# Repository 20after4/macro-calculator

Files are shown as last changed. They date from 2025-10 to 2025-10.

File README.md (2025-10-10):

# MacroCalculator

Custom Mechanical USB Keypad + Standalone Calculator written in MicroPython

## Hardware:

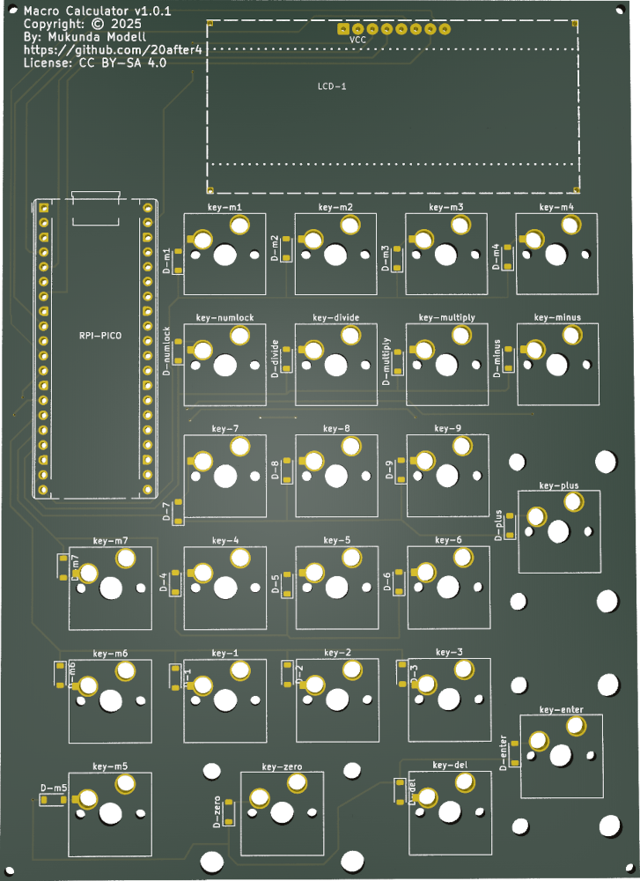
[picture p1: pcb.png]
Illustration of the circuit board PCB
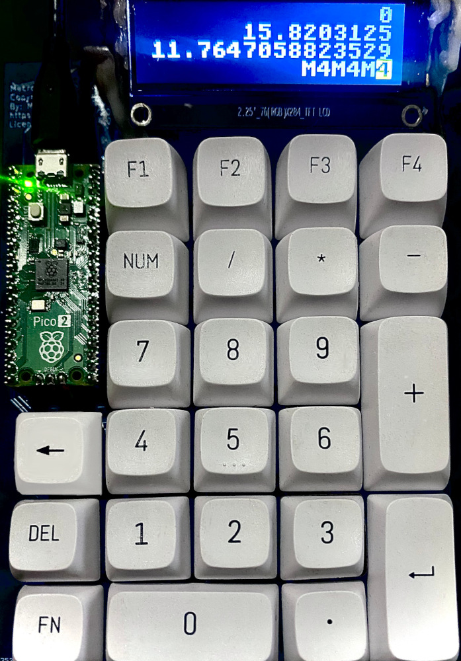
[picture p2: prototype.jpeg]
Photo of the prototype Prototype
 

* Custom 24 Key Matrix PCB
    * Supports hot-swapable MX-style key switches
    * Hand solderable (Difficulty: medium-high due to small surface mount diodes)
    * Standard PC Numpad Keys
    * 7 extra macro keys
    * Sockets for MCU and LCD via pin headers.
* RPi Pico 2 (RP2350 MCU)
* 72x284 resolution ST7789 LCD Screen: 16px font = 4 lines x 17 characters

## Software / Firmware

Custom Python App running on [lvgl/lv_micropython](https://github.com/lvgl/lv_micropython) firmware.

The NumLock key toggles between two modes:

* Calc mode:
  * Basic calculator functionality
  * 17 digits of decimal precision
  * Basic expression evaluation
  * Named variables assignable to the macro keys
  * Scrollable history buffer
* Keypad mode:
  * Basic USB HID Numpad
  * Macro keys programmable with MicroPython for nearly unlimited flexibility.

### Acknoledgements

Here I credit the projects that made this one possible. This project draws on these other open source projects for inspiration and some of the components used in developing macro-calc:

* Raspberry Pi Pico - The RP2040 and successors have proven to be a very affordable and accessible microcontroller development platform which has significantly lowered the barrier to entry for embedded development.
* [MicroPython](https://www.micropython.org/): The programming language runtime and embedded firmware infrastructure.
* [LVGL](https://lvgl.io/) - Graphics API for embedded devices which I've utilized in order to support the LCD display in this project.
* [lvgl/lv_micropython](https://github.com/lvgl/lv_micropython) is a fork of micropython designed for building microcontroller Firmware with integrated LVGL graphics capabilities compiled into the micropython runtime. This is the foundation I've used to build the firmware for this project.
* [lvgl_micropython](https://github.com/lvgl-micropython/lvgl_micropython) deserves an honorable mention. This is an alternative fork, based on the previously mentioned project.  Although I don't currently use this fork to build my firmware, I have learned quite a lot about TFT Display chips from studying their source code, issues and discussions on github and on the lvgl forums.
* [mpy-dev/micropython-decimal-number](https://github.com/mpy-dev/micropython-decimal-number) provides
  a basis for sane decimal arithmatic. This has proven very helpful for the calculator portion of this project. Floating point math isn't a good fit for a general purpose calculator.

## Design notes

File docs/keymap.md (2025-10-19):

keymap.py contains a list with all of the key metadata.

The layout of the keys list is arranged according to the physical key matrix
starting at the bottom row with F17 through ENTER.   Positions that are not
connected to a key switch are filled with the value None so that the matrix
remains rectangular.   There are 6 rows with 5 columns.  There are however,
only 4 keys in each matrix column. Coercing the data structure to match the
physical wiring of the key matrix allows for more efficient key scanning.
Specifically, it allows us to deduce the keycode from simply multipling
row * column  to get the index into the keys list so that key metadata can
be accessed with a quick lookup, without scanning the array and without the
memory overhead of using a hash table.

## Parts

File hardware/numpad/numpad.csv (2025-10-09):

Id | Designator | Footprint | Quantity | Designation | Supplier and ref
1 | LCD-1 | 2.25in LCD DISPLAY 284x76 | 1 | 2.25in LCD
2 | key-m6,key-m5,key-2,key-del,key-divide,key-m3,key-m1,key-9,key-4,key-multiply,key-6,key-m4,key-m2,key-minus,key-8,key-5,key-m7,key-3,key-1,key-numlock,key-7 | SW_Cherry_MX_1.00u_PCB_HOTSWAP | 21 | SW_Cherry_MX_1.00u_PCB_HOTSWAP
3 | D-m1,D-m2,D-m7,D-enter,D-m6,D-divide,D-m5,D-m4,D-7,D-m3,D-multiply,D-3,D-6,D-plus,D-8,D-1,D-9,D-del,D-numlock,D-2,D-4,D-5,D-minus,D-zero | D_SOD-123 | 24 | D_SOD-123
4 | key-enter,key-plus | SW_Cherry_MX_2.00u_Vertical_PCB | 2 | SW_Cherry_MX_2.00u_Vertical_PCB
5 | RPI-PICO | RaspberryPi_Pico_Common_THT | 1 | RaspberryPi_Pico_Common_THT
6 | key-zero | SW_Cherry_MX_2.00u_PCB | 1 | SW_Cherry_MX_2.00u_PCB

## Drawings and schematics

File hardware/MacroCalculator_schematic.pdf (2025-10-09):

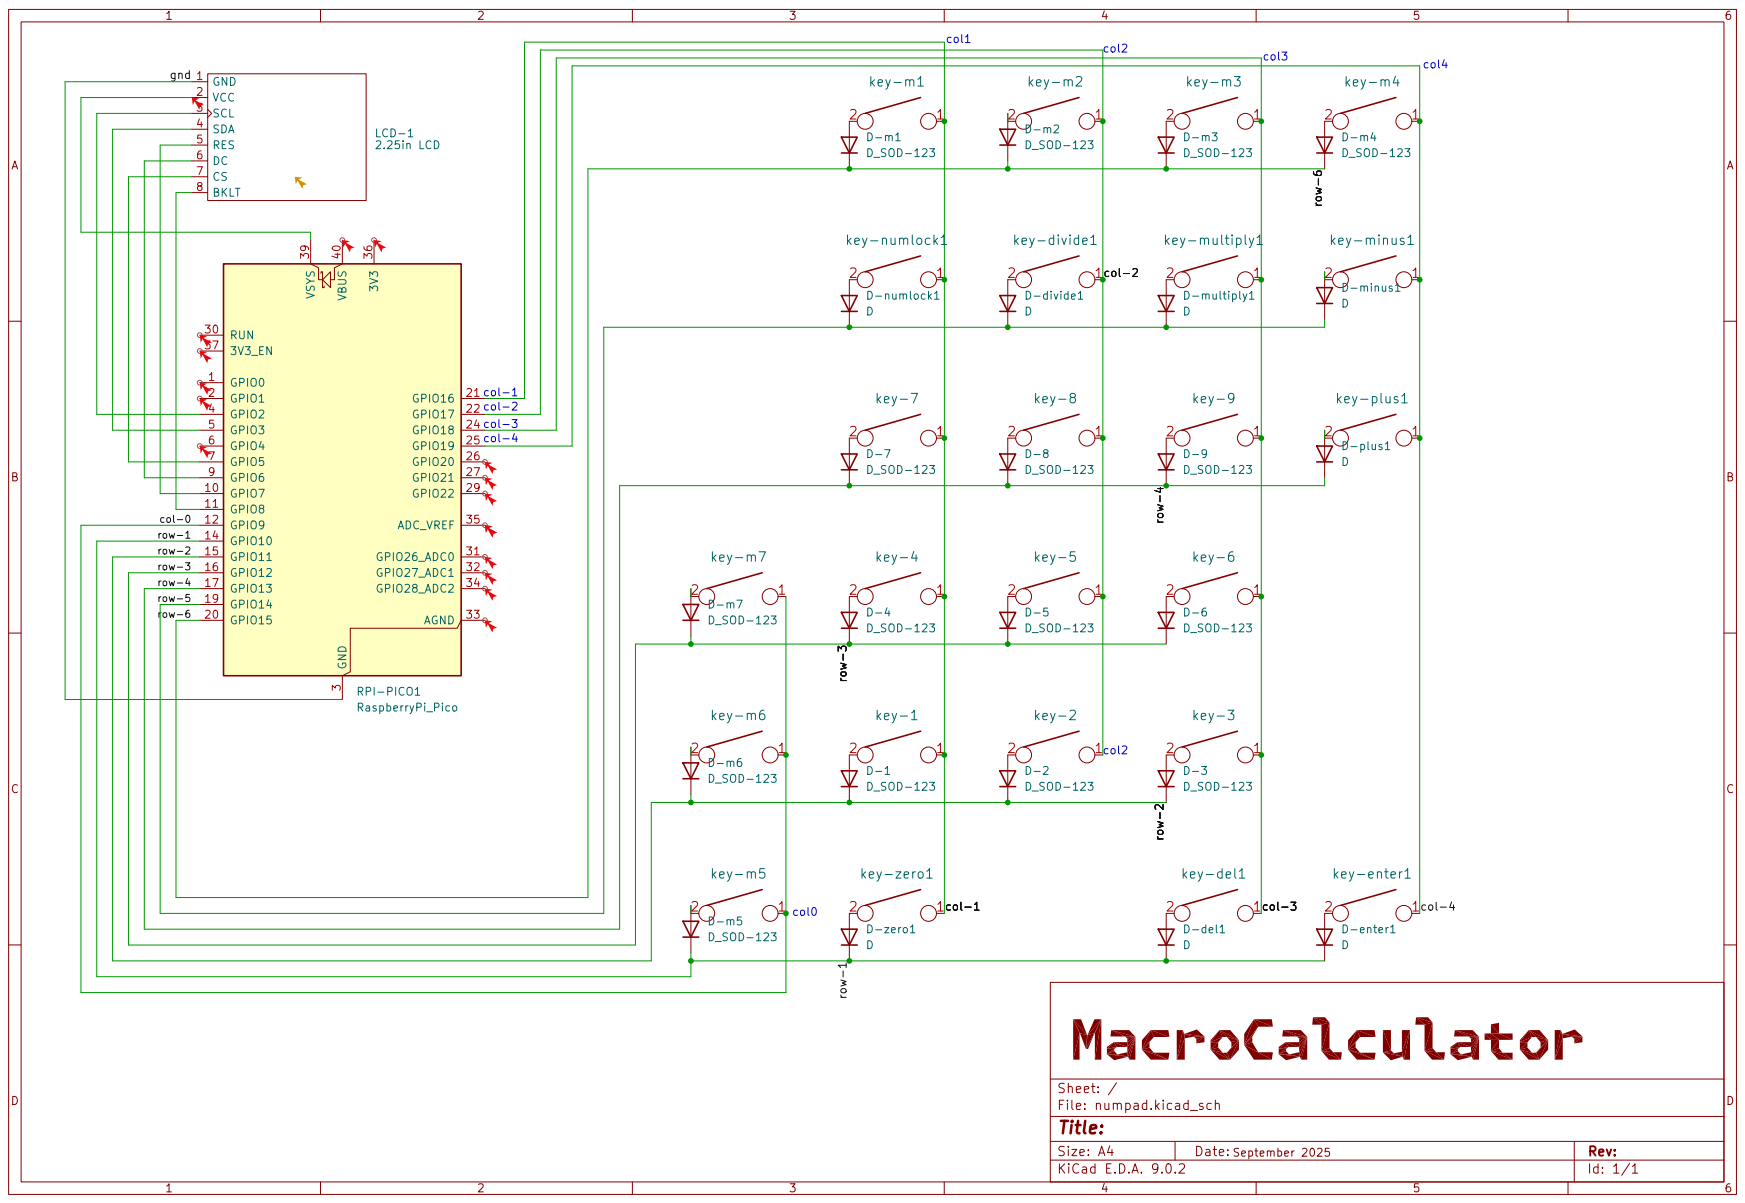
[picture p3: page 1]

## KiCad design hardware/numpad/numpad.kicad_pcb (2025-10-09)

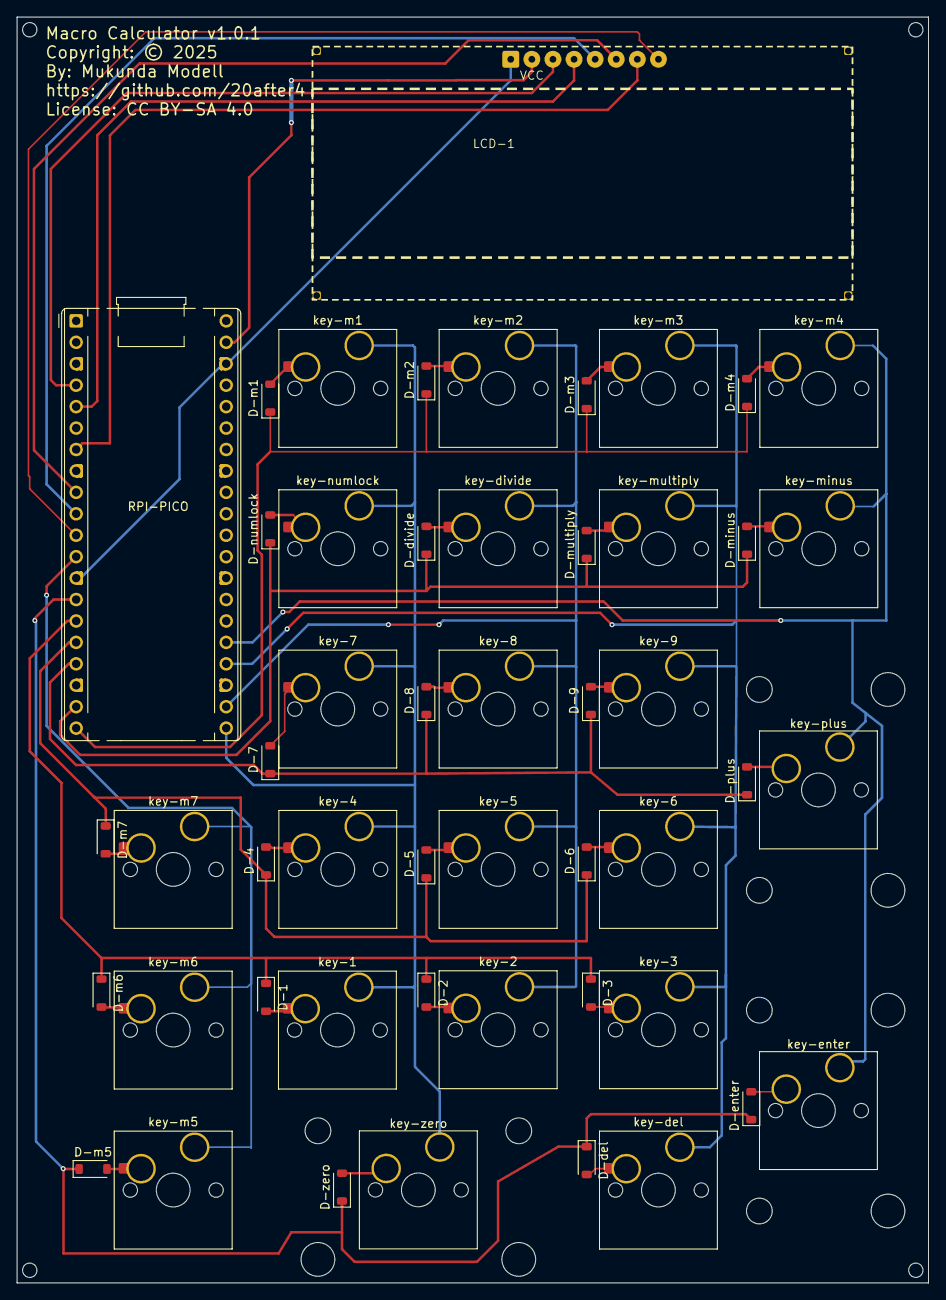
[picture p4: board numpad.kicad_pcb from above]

Board: 2 copper layers, 108.0 x 150.0 mm, 50 parts (0 on the bottom side), 43 nets.

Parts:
D-1, D-2, D-3, D-4, D-5, D-6, D-7, D-8, D-9: D_SOD-123
D-del: D_SOD-123
D-divide: D_SOD-123
D-enter: D_SOD-123
D-m1, D-m2, D-m3, D-m4, D-m5, D-m6, D-m7: D_SOD-123
D-minus: D_SOD-123
D-multiply: D_SOD-123
D-numlock: D_SOD-123
D-plus: D_SOD-123
D-zero: D_SOD-123
LCD-1: 2.25in LCD; 2.25in LCD DISPLAY 284x76
RPI-PICO: RaspberryPi_Pico_Common_THT
key-1, key-2, key-3, key-4, key-5, key-6, key-7, key-8, key-9: SW_Cherry_MX_1.00u_PCB_HOTSWAP
key-del: SW_Cherry_MX_1.00u_PCB_HOTSWAP
key-divide: SW_Cherry_MX_1.00u_PCB_HOTSWAP
key-enter: SW_Cherry_MX_2.00u_Vertical_PCB
key-m1, key-m2, key-m3, key-m4, key-m5, key-m6, key-m7: SW_Cherry_MX_1.00u_PCB_HOTSWAP
key-minus: SW_Cherry_MX_1.00u_PCB_HOTSWAP
key-multiply: SW_Cherry_MX_1.00u_PCB_HOTSWAP
key-numlock: SW_Cherry_MX_1.00u_PCB_HOTSWAP
key-plus: SW_Cherry_MX_2.00u_Vertical_PCB
key-zero: SW_Cherry_MX_2.00u_PCB

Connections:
LCD-BACKLIGHT: LCD-1.8, RPI-PICO.11
LCD-CS: LCD-1.7 (BKLT), RPI-PICO.7
LCD-DC: LCD-1.6 (CS), RPI-PICO.9
LCD-RESET: LCD-1.5 (RES), RPI-PICO.10
unnamed: D-1.2 (A), key-1.2
unnamed: D-2.2 (A), key-2.2
unnamed: D-3.2 (A), key-3.2
unnamed: D-4.2 (A), key-4.2
unnamed: D-5.2 (A), key-5.2
unnamed: D-6.2 (A), key-6.2
unnamed: D-7.2 (A), key-7.2
unnamed: D-8.2 (A), key-8.2
unnamed: D-9.2 (A), key-9.2
unnamed: D-m1.2 (A), key-m1.2
unnamed: D-m2.2 (A), key-m2.2
unnamed: D-m3.2 (A), key-m3.2
unnamed: D-m4.2 (A), key-m4.2
unnamed: D-m5.2 (A), key-m5.2
unnamed: D-m6.2 (A), key-m6.2
unnamed: D-m7.2 (A), key-m7.2
SPI-CLK: LCD-1.3 (SCL), RPI-PICO.4
SPI-DATA: LCD-1.4 (SDA), RPI-PICO.5
col-0: RPI-PICO.12, key-m5.1, key-m6.1, key-m7.1
col-1: RPI-PICO.21, key-1.1, key-4.1, key-7.1, key-m1.1, key-numlock.1, key-zero.1
col-2: RPI-PICO.22, key-2.1, key-5.1, key-8.1, key-divide.1, key-m2.1
col-3: RPI-PICO.24, key-3.1, key-6.1, key-9.1, key-del.1, key-m3.1, key-multiply.1
col-4: RPI-PICO.25, key-enter.1, key-m4.1, key-minus.1, key-plus.1
gnd: LCD-1.1 (GND), RPI-PICO.13, RPI-PICO.38
key-del: D-del.2, key-del.2
key-divide: D-divide.2, key-divide.2
key-enter: D-enter.2, key-enter.2
key-minus: D-minus.2, key-minus.2
key-multiply: D-multiply.2, key-multiply.2
key-numlock: D-numlock.2, key-numlock.2
key-plus: D-plus.2, key-plus.2
key-zero: D-zero.2, key-zero.2
row-1: D-del.1, D-enter.1, D-m5.1 (K), D-zero.1, RPI-PICO.14
row-2: D-1.1 (K), D-2.1 (K), D-3.1 (K), D-m6.1 (K), RPI-PICO.15
row-3: D-4.1 (K), D-5.1 (K), D-6.1 (K), D-m7.1 (K), RPI-PICO.16
row-4: D-7.1 (K), D-8.1 (K), D-9.1 (K), D-plus.1, RPI-PICO.17
row-5: D-divide.1, D-minus.1, D-multiply.1, D-numlock.1, RPI-PICO.19
row-6: D-m1.1 (K), D-m2.1 (K), D-m3.1 (K), D-m4.1 (K), RPI-PICO.20
vcc: LCD-1.2 (VCC), RPI-PICO.39

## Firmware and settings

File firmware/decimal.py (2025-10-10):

# from https://github.com/mpy-dev/micropython-decimal-number
# MIT License

import sys

if sys.implementation.name == "cpython":        # micropython does not include 'typing' module
    from typing import Tuple
if sys.implementation.name == "micropython":    # Just in case...
    pass


class DecimalNumber:
    """DecimalNumber is a class for decimal floating point arithmetic with arbitrary precision."""
    VERSION = (1, 0, 0)
    VERSION_NAME = "v1.0.0 - August 2021"
    DEFAULT_SCALE: int = 16
    DECIMAL_SEP: str = "."
    THOUSANDS_SEP: str = ","
    USE_THOUSANDS_SEP: bool = False
    PI_NUMBER: int = 31415926535897932384626433832795028841971693993751058209749445923078164062862089986280348253421170679
    PI_SCALE: int = 100
    E_NUMBER: int = 27182818284590452353602874713526624977572470936999595749669676277240766303535475945713821785251664274
    E_SCALE: int = 100
    LN2_NUMBER: int = 6931471805599453094172321214581765680755001343602552541206800094933936219696947156058633269964186875
    LN2_SCALE: int = 100
    _scale: int = DEFAULT_SCALE

    def __init__(self, number=0, decimals: int = 0) -> None:
        """Initialization of a DecimalNumber.
        These are this posibilities:
        1) No parameters => number = 0.         Example: DecimalNumber()
        2) An integer => number = integer.      Example: DecimalNumber(1)
        3) Two integers => number and decimals. Example: Decimal(12345, 3) => Number = 12.345
        4) One string that contains the number. Example: Decimal("12.345") => Number = 12.345
        """
        if isinstance(number, int):
            self._is_positive: bool = (number >= 0)
            self._number: int = number if number >= 0 else -number
            if decimals >= 0:
                self._num_decimals: int = decimals
            else:
                raise DecimalNumberExceptionMathDomainError(
                    "__init__: the number of decimals must be positive")
            self._reduce_to_scale()
        elif isinstance(number, str):
            self.copy_from(DecimalNumber._from_string(number))
        else:
            raise DecimalNumberExceptionBadInit(
                "Only 'int' or 'str' instances are allowed for initialization")

    @classmethod
    def pi(cls) -> "DecimalNumber":
        """Calculation of PI using the very fast algorithm present on the
        documentation of the module "decimal" of the Python Standard Library:
        https://docs.python.org/3/library/decimal.html#recipes
        """
        # If it is precalculated
        if DecimalNumber.PI_SCALE >= DecimalNumber.get_scale():
            s: DecimalNumber = DecimalNumber(DecimalNumber.PI_NUMBER, DecimalNumber.PI_SCALE)
        else:
            # Calculates PI
            scale: int = DecimalNumber.get_scale()
            # extra digits for intermediate steps
            DecimalNumber.set_scale(scale + 4)
            lasts = DecimalNumber(0)
            t = DecimalNumber(3)
            s = DecimalNumber(3)
            n = DecimalNumber(1)
            na = DecimalNumber(0)
            d = DecimalNumber(0)
            da = DecimalNumber(24)
            eight = DecimalNumber(8)
            thirtytwo = DecimalNumber(32)
            while s != lasts:
                lasts.copy_from(s)
                n += na
                na += eight
                d += da
                da += thirtytwo
                t = (t * n) / d
                s += t
            DecimalNumber.set_scale(scale)
            # Stores the calculated PI
            DecimalNumber.PI_NUMBER = (+s)._number  # + adjusts to the scale
            DecimalNumber.PI_SCALE = (+s)._num_decimals
        return +s

    @classmethod
    def e(cls) -> "DecimalNumber":
        """Calculation of e.
        It uses the Taylor series:
            e = 1/0! + 1/1! + 1/2! + 1/3! + ... + 1/n!
        """
        # If it is precalculated
        if DecimalNumber.E_SCALE >= DecimalNumber.get_scale():
            e: DecimalNumber = DecimalNumber(DecimalNumber.E_NUMBER, DecimalNumber.E_SCALE)
        else:
            scale: int = DecimalNumber.get_scale()
            # extra digits for intermediate steps
            DecimalNumber.set_scale(scale + 4)

            i = DecimalNumber(0)
            f = DecimalNumber(1)
            e = DecimalNumber(1)
            e2 = DecimalNumber(0)
            one = DecimalNumber(1)
            while e2 != e:
                e2.copy_from(e)
                i += one		# counter
                f *= i
                t = one / f
                e += t

            DecimalNumber.set_scale(scale)
            # Stores the calculated E
            DecimalNumber.E_NUMBER = (+e)._number  # + adjusts to the scale
            DecimalNumber.E_SCALE = (+e)._num_decimals
        return +e

    @classmethod
    def ln2(cls) -> "DecimalNumber":
        """Calculation of ln(2).
        ln(2) = -ln(1/2) = -ln(1 - 1/2)
        It uses the Taylor series:
            ln(1-x) = -x -x²/2 - x³/3 ...
            ln(2) = x + x²/2 + x³/3 ... for x = 1/2
        """
        # If it is precalculated
        if DecimalNumber.LN2_SCALE >= DecimalNumber.get_scale():
            e: DecimalNumber =  DecimalNumber(DecimalNumber.LN2_NUMBER, DecimalNumber.LN2_SCALE)
        else:
            scale: int = DecimalNumber.get_scale()
            DecimalNumber.set_scale(scale + 4) # extra digits for intermediate steps

            i = DecimalNumber(0)    # counter
            half = DecimalNumber(5, 1) # 0.5
            x = DecimalNumber(1)
            one = DecimalNumber(1)
            e = DecimalNumber(0)
            e2 = DecimalNumber(1)
            while e2 != e:
                e2.copy_from(e)
                i += one
                x *= half
                e += x / i

            DecimalNumber.set_scale(scale)
            # Stores the calculated LN2
            DecimalNumber.LN2_NUMBER = (+e)._number  # + adjusts to the scale
            DecimalNumber.LN2_SCALE = (+e)._num_decimals
        return +e

    def exp(self, inc_scale: bool = True) -> "DecimalNumber":
        """Calculates exp(n)
        Works for any x, but for speed, it should have |x| < 1.
        For an arbitrary number, to guarantee that |x| < 1, it uses:
            exp(x) = exp(x - m * log(2)) * 2 ^ m ; where m = floor(x / log(2))

        Scale is increased if 'inc_false' is True.
        """
        scale = DecimalNumber.get_scale()
        # Calculating the necessary extra scale:
        extra = (abs(self) / DecimalNumber("2.3")).to_int_round() + 10
        DecimalNumber.set_scale(scale + extra)
        if abs(self) <= 1:
            r = DecimalNumber._exp_lt_1(self, inc_scale)
        else:
            m = (self / DecimalNumber.ln2()).to_int_truncate()
            r = DecimalNumber._exp_lt_1(self - m * DecimalNumber.ln2()) * (2 ** m)

        DecimalNumber.set_scale(scale)
        return +r

    @staticmethod
    def _exp_lt_1(n: "DecimalNumber", inc_scale: bool = True) -> "DecimalNumber":
        """ Auxiliary function to calculates exp(n)
        Expects |n| < 1 to converge rapidly
        """
        if n == 1:
            e = DecimalNumber.e()
        elif n == -1:
            e = 1 / DecimalNumber.e()
        else:
            i = DecimalNumber(0)
            x = DecimalNumber(1)
            f = DecimalNumber(1)
            e = DecimalNumber(1)
            e2 = DecimalNumber(0)
            one = DecimalNumber(1)
            while e2 != e:
                e2.copy_from(e)
                i += one		# counter
                x *= n
                f *= i
                t = x / f
                e += t

        # if inc_scale:
        #     DecimalNumber.set_scale(scale)
        return +e

    def ln(self) -> "DecimalNumber":
        """Calculates ln(n)
        Newton's method is used to solve: e**a - x = 0 ; a = ln(x)
        """
        if self == 1:
            return DecimalNumber(0)
        if self == 0:
            raise DecimalNumberExceptionMathDomainError("ln(0) = -Infinite")
        if self < 0:
            raise DecimalNumberExceptionMathDomainError("ln(x) exists for x > 0")
        n = self
        scale: int = DecimalNumber.get_scale()

        # Estimate first value
        DecimalNumber.set_scale(10) # Low scale for this is enough
        e = DecimalNumber.e()
        y0 = DecimalNumber(0)
        y1 = DecimalNumber(1)
        one = DecimalNumber(1)
        p: DecimalNumber = e.clone()
        while p < n:
            y1 += one
            p *= e

        DecimalNumber.set_scale(scale) # Restores scale
        DecimalNumber.set_scale(DecimalNumber.get_scale() + 10) # extra digits for intermediate steps
        two = DecimalNumber(2)
        while y0 != y1:
            y0.copy_from(y1)
            y1 = y0 + two * ((n - y0.exp(False)) / (n + y0.exp(False)))

        DecimalNumber.set_scale(scale)
        return +y1

    def sin(self) -> "DecimalNumber":
        """Calculates sin(x). x = radians
        It uses the Taylor series: sin(x) = x - x³/3! + x⁵/5! - x⁷/7! ...
        """
        x = self.clone()
        scale: int = DecimalNumber.get_scale()
        DecimalNumber.set_scale(scale + 4) # extra digits for intermediate steps

        negative_radians: bool = (x < 0)
        if negative_radians:
            x = -x
        # Calculates x mod 2π
        pi = DecimalNumber.pi()
        f: int = (x / (pi * 2)).to_int_truncate()
        if f > 0:
            x -= f * 2 * pi

        # Determines the quadrant and reduces the range of x to 0 - π/2
        # sin(-x) = -sin(x) ; cos(-x) = cos(x) ; tan(-x) = -tan(x)
        half_pi = pi / 2
        r = half_pi.clone()
        quadrant: int = 1
        while x > r:
            r += half_pi
            quadrant += 1

        if quadrant == 2:
            x = pi - x
        elif quadrant == 3:
            x = x - pi
        elif quadrant == 4:
            x = 2 * pi - x

        i = DecimalNumber(1)    # counter
        two = DecimalNumber(2)
        n = x.clone()
        d = DecimalNumber(1)
        s = DecimalNumber(1)
        e = n.clone()
        e2 = DecimalNumber(0)
        while e2 != e:
            e2.copy_from(e)
            i += two
            n *= x * x
            d *= i * (i - 1)
            s = -s
            e += (n * s) / d

        if quadrant > 2:
            e = -e
        if negative_radians:
            e = -e

        DecimalNumber.set_scale(scale)
        return +e

    def cos(self) -> "DecimalNumber":
        """Calculates cos(x). x = radians
        It uses the Taylor series: cos(x) = 1 - x²/2! + x⁴/4! - x⁶/6! ...
        """
        x = self.clone()
        scale: int = DecimalNumber.get_scale()
        DecimalNumber.set_scale(scale + 4) # extra digits for intermediate steps

        if (x < 0): # cos(-x) = cos(x)
            x = -x

        # Calculates x mod 2π
        pi = DecimalNumber.pi()
        f: int = (x / (pi * 2)).to_int_truncate()
        if f > 0:
            x -= f * 2 * pi

        # Determines the quadrant and reduces the range of x to 0 - π/2
        half_pi = pi / 2
        r = half_pi.clone()
        quadrant: int = 1
        while x > r:
            r += half_pi
            quadrant += 1

        if quadrant == 2:
            x = pi - x
        elif quadrant == 3:
            x = x - pi
        elif quadrant == 4:
            x = 2 * pi - x

        i = DecimalNumber(1)    # counter
        two = DecimalNumber(2)
        n = DecimalNumber(1)
        d = DecimalNumber(1)
        s = DecimalNumber(1)
        e = n.clone()
        e2 = DecimalNumber(0)
        while e2 != e:
            e2.copy_from(e)
            n *= x * x
            d *= i * (i + 1)
            i += two
            s = -s
            e += (n * s) / d

        if quadrant == 2 or quadrant == 3:
            e = -e

        DecimalNumber.set_scale(scale)
        return +e

    def tan(self) -> "DecimalNumber":
        """Calculates tan(x) = sin(x) / cos(x). x = radians """
        x = self.clone()

        # Calculates x mod 2π
        pi = DecimalNumber.pi()
        f: int = (x / (pi * 2)).to_int_truncate()
        if f > 0:
            x -= f * 2 * pi

        half_pi = pi / 2
        three_halves_pi = (3 * pi) / 2
        # Determines the quadrant
        r = half_pi.clone()
        quadrant: int = 1
        while x > r:
            r += half_pi
            quadrant += 1

        # tan(x) = sin(x) / cos(x) ; if cos(x) == 0  =>  tan(x) = ∞

        if self == half_pi or self == three_halves_pi:
            raise DecimalNumberExceptionDivisionByZeroError("tan(x) = ±Infinite")
        else:
            scale: int = DecimalNumber.get_scale()
            DecimalNumber.set_scale(scale + 4)
            s = x.sin()
            c = x.cos()
            if c == 0:
                DecimalNumber.set_scale(scale)
                raise DecimalNumberExceptionDivisionByZeroError("tan(x) = ±Infinite")
            else:
                t = s / c
                DecimalNumber.set_scale(scale)
                return +t

    def asin(self) -> "DecimalNumber":
        """Calculates asin(x)
        It uses the Taylor series: arcsin(x) = x + 3x³/6 + 15x⁵/336 + ...
        It converges very slowly for |x| near 1. To avoid values near 1:
        If |n| between 0 and 0.707: arcsin(x) is calculated using the series.
        if |n| between 0.707 and 1: arcsin(x) is calculated as pi/2 - arcsin( sqrt(1 - x²) )
        This guarantees arcsin(x) using series with x <= 0.707 ; (sqrt(1/2)).
        """
        if self >= -1 and self <= 1:
            if self == -1:
                return -(DecimalNumber.pi() / 2)
            elif self == 1:
                return (DecimalNumber.pi() / 2)
            elif self == 0:
                return DecimalNumber(0)

            scale: int = DecimalNumber.get_scale()
            DecimalNumber.set_scale(DecimalNumber.get_scale() + 4) # extra digits for intermediate steps

            trick: bool = False
            if abs(self) > DecimalNumber("0.707"):
                trick = True
                x = (1 - self * self).square_root()
            else:
                x = self.clone()

            i = DecimalNumber(1)    # counter
            one = DecimalNumber(1)
            two = DecimalNumber(2)
            four = DecimalNumber(4)
            n = DecimalNumber(1)
            d = DecimalNumber(1)
            n2 = x.clone()
            e = x.clone()
            e2 = DecimalNumber(0)
            counter: int = 0
            while e2 != e:
                e2.copy_from(e)
                n *= i
                i += two
                d *= i - one
                n2 *= x * x
                e += (n * n2) / (d * i)

            if trick:
                if self._is_positive:
                    e = DecimalNumber.pi() / 2 - e
                else:
                    e = e - DecimalNumber.pi() / 2

            DecimalNumber.set_scale(scale)
            return +e
        else:
            raise DecimalNumberExceptionMathDomainError("asin(x) admits -1 <= x <= 1 only")

    def acos(self) -> "DecimalNumber":
        """Calculates acos(x)
        It uses the equivalence: acos(x) = π/2 - asin(x)
        """
        if self >= -1 and self <= 1:
            scale: int = DecimalNumber.get_scale()
            DecimalNumber.set_scale(DecimalNumber.get_scale() + 4) # extra digits for intermediate steps

            a = (DecimalNumber.pi() / 2) - self.asin()

            DecimalNumber.set_scale(scale)
            return +a
        else:
            raise DecimalNumberExceptionMathDomainError("acos(x) admits -1 <= x <= 1 only")

    def atan(self) -> "DecimalNumber":
        """Calculates atan(x)
        It uses: atan(x) = asin( x / sqrt(1 + x²) )
        """
        scale: int = DecimalNumber.get_scale()
        DecimalNumber.set_scale(DecimalNumber.get_scale() + 4) # extra digits for intermediate steps
        one = DecimalNumber(1)
        v = self / (one + self * self).square_root()
        a = v.asin()

        DecimalNumber.set_scale(scale)
        return +a

    @staticmethod
    def atan2(y: "DecimalNumber", x: "DecimalNumber") -> "DecimalNumber":
        """Calculates atan2(y, x), 2-argument arctangent
        It uses:
            if x > 0:   atan(y/x)
            if x < 0:
                        if y >= 0:  atan(y/x) + pi
                        if y < 0:   atan(y/x) - pi
            if x = 0:
                        if y > 0:   +pi/2
                        if y < 0:   -pi/2
                        if y = 0:   undefined
        """
        if isinstance(y, int):
            y = DecimalNumber(y)
        if isinstance(x, int):
            x = DecimalNumber(x)

        scale: int = DecimalNumber.get_scale()
        DecimalNumber.set_scale(DecimalNumber.get_scale() + 4) # extra digits for intermediate steps
        r = DecimalNumber()
        if x == 0:
            if y == 0:
                raise DecimalNumberExceptionMathDomainError(
                    "Undefined value for atan2(0, 0)")
            elif y > 0:
                r = (DecimalNumber.pi() / 2)
            else:
                r = (-DecimalNumber.pi() / 2)
        else:
            r = (y / x).atan()
            if x < 0:
                if y >= 0:
                    r += DecimalNumber.pi()
                else:
                    r -= DecimalNumber.pi()

        DecimalNumber.set_scale(scale)
        return +r

    @staticmethod
    def version() -> str:
        """Returns a tuple (MINOR, MINOR, PATCH) with the version of DecimalNumber"""
        return DecimalNumber.VERSION

    @staticmethod
    def version_name() -> str:
        """Returns a string with the version of DecimalNumber"""
        return DecimalNumber.VERSION_NAME

    @staticmethod
    def set_scale(num_digits: int) -> None:
        """Sets the scale.
        Scale is a class value, the maximum number of decimals that a DecimalNumber can have.
        The default value is 16. The maximum value is only limited by the available
        memory and computer power."""
        if num_digits >= 0:
            DecimalNumber._scale = num_digits
        else:
            raise DecimalNumberExceptionMathDomainError(
                "set_scale: scale must be positive")

    @staticmethod
    def get_scale() -> int:
        """Gets the current scale value."""
        return DecimalNumber._scale

    @staticmethod
    def _parse_number(number: str) -> Tuple[bool, int, int]:
        """This is a static and auxiliary method to parse a string containing
        a number. If the string is parsed as a number, it returns three values:
            True --> string correctly parsed as number.
            Integer containing all the digits of the number.
            Integer representing the number of decimals.
        For example: "-12345.678" will be parsed and the values returned will be:
            (True, -12345678, 3)
        If the parsing fails, it returns (Falsem 0, 0).
        Note: this is faster than using a regular expression. Also, when using
        the regular expression "^\-?[0-9]+\.?[0-9]*" and exception was raised when
        using micropython when the string "number" was long.
        """
          # True: correct
        # Note:
        step: int = 1   # 1: '-', 2: [0-9], 3: '.', 4: [0-9]
        position: int = 0
        integer_number: int = 0
        is_positive: bool = True
        num_decimals: int = 0
        number = tuple(number,)     # Faster than indexing the string
        length: int = len(number)
        digits: str = "0123456789"
        last_valid: int = 0
        while position < length:
            if step == 1:
                if number[position] == '-':
                    is_positive = False
                    position += 1
                step = 2
            elif step == 2:
                if digits.find(number[position]) != -1:  # [0-9]+
                    integer_number = integer_number * \
                        10 + int(number[position])
                    position += 1
                    last_valid = position
                else:
                    step = 3
            elif step == 3:
                if number[position] == DecimalNumber.DECIMAL_SEP:
                    position += 1
                    last_valid = position
                step = 4
            elif step == 4:
                if digits.find(number[position]) != -1:  # [0-9]*
                    integer_number = integer_number * \
                        10 + int(number[position])
                    num_decimals += 1
                    position += 1
                    last_valid = position
                else:
                    break
        if last_valid == length:
            if not is_positive:
                integer_number = -integer_number
            return (True, integer_number, num_decimals)
        else:
            return (False, 0, 0)

    @staticmethod
    def _from_string(number: str) -> "DecimalNumber":
        """static and auxiliary method to create a DecimalNumber from a string."""
        correct, integer_number, num_decimals = DecimalNumber._parse_number(
            number)
        if not correct:
            raise DecimalNumberExceptionParseError(
                "Syntax error parsing '{0}'".format(number))
        else:
            n = DecimalNumber(integer_number, num_decimals)
        return n
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

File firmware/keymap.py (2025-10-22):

from machine import Pin
from array import array
import time
from settimeout import setTimeout, cancelTimeout
# This keypad has a contiguous series of keys (KEYPAD_KEY_IDS) starting at 0x4A:
_KEYPAD_KEY_OFFS = const(0x4A)

# See HID Usages and Descriptions 1.4, section 10 Keyboard/Keypad Page (0x07)
#
# https://usb.org/sites/default/files/hut1_21.pdf
#

# these const names are defined for convenience and easier identification in
# the rest of the codebase when referencing keys by their int keycode.
# The mapping of keycodes to the physical key matrix is handled with the keys
# list defined below.

HOME = const(0x4A)
PGUP = const(0x4B)
DEL = const(0x4C)
END = const(0x4D)
PGDN = const(0x4E)
RIGHT = const(0x4F)
LEFT = const(0x50)
DOWN = const(0x51)
UP = const(0x52)
NUMLOCK = const(0x53)
DIVIDE = const(0x54)
MULTIPLY = const(0x55)
SUBTRACT = const(0x56)
ADD = const(0x57)
ENTER = const(0x58)
KP1 = const(0x59)
KP2 = const(0x5A)
KP3 = const(0x5B)
KP4 = const(0x5C)
KP5 = const(0x5D)
KP6 = const(0x5E)
KP7 = const(0x5F)
KP8 = const(0x60)
KP9 = const(0x61)
KP0 = const(0x62)
PERIOD = const(0x63)
EQUAL = const(0x67)
F13 = const(0x68)
F14 = const(0x69)
F15 = const(0x6A)
F16 = const(0x6B)
F17 = const(0x6C)
F18 = const(0x6D)
F19 = const(0x6E)
F20 = const(0x6F)

RELEASE = const(0)
PRESS = const(1)
LONGPRESS = const(2)

# rows and cols contain all of the gpio pins that are connected to
# the key matrix. Rows are inputs and columns are outputs.
# When scanning the keys, we enable each column one by one, then read all
# rows to see which keys are pressed in the given column.
# Note: We are using pulldown on the rows and this is problematic on the
# RP2350, however, a workaround has been implemented in the key scanning code.

rows = [
        Pin(10, Pin.IN, Pin.PULL_DOWN),
        Pin(11, Pin.IN, Pin.PULL_DOWN),
        Pin(12, Pin.IN, Pin.PULL_DOWN),
        Pin(13, Pin.IN, Pin.PULL_DOWN),
        Pin(14, Pin.IN, Pin.PULL_DOWN),
        Pin(15, Pin.IN, Pin.PULL_DOWN)
]

cols = [ Pin(9, Pin.OUT),
        Pin(16, Pin.OUT),
        Pin(17, Pin.OUT),
        Pin(18, Pin.OUT),
        Pin(19, Pin.OUT)
]


class KeyboardState:
  state = array('b', [0,0,0,0,0,0,0,0,0,0,0,0,0,0,0,0,0,0,0,0,0,0,0,0,0,0,0,0,0,0,0])
  layer = 0
  instance = None
  NumLock = False

  def __init__(self):
    self.app = None
    pass

  @classmethod
  def singleton(cls):
    if cls.instance is None:
      cls.instance = KeyboardState()
    return cls.instance

  def action(self, key, action, symbol=None):
    if symbol is None:
      symbol = key.symbol

    if self.app is not None:
      self.app.action(key, action, symbol)


keyboard = KeyboardState.singleton()

class Key:
  lower_key = None

  def __init__(self, scancode, name, symbol, shifted=None, layers=None ):
    global keyboard
    self.keyboard = keyboard
    self.scancode = scancode
    self.name = name
    self.symbol = symbol
    self.shifted = shifted
    self.keydown=0
    self.layers = []
    if layers is not None:
      self.add_layers(layers)


  def add_layers(self, layers):
    if isinstance(layers, list):
      self.layers.extend(layers)
    else:
      self.layers.append(layers)


  def set_lower(self, key):
    self.lower_key = key

  def update(self, keydown):
    if self.keydown != keydown:
      self.keydown = keydown

      res = False
      if keydown == 0:
        for action in self.layers:
          res = action.on_release()
          if res:
            return res
        if not res:
          res = self.on_release()
        if (not res) and self.lower_key is not None:
          res = self.lower_key.on_release()
      else:
        for action in self.layers:
          res = action.on_press()
          if res:
            return res
        if not res:
          res = self.on_press()
        if (not res) and self.lower_key is not None:
          res = self.lower_key.on_press()
      return res
    else:
      return True

  def on_press(self):
    return False

  def on_release(self):
    return False

  def __getitem__(self, index):
    if index==0:
      return self.scancode
    elif index==1:
      return self.name
    elif index==2:
      return self.symbol
    elif index==3:
      return self.shifted
    elif isinstance(index, slice):
      tmp = (self.scancode, self.name, self.symbol, self.shifted)
      start, stop, step = index.indices(len(self))
      return tmp[start:stop:step]
    else:
      raise(IndexError('Key: Invalid index'))

  def __len__(self):
    if self.shifted is not None:
      return 4
    else:
      return 3

  def __repr__(self):
    return f"Key({self.scancode}, {self.name}, {self.symbol})"

  def get_symbol(self):
    if keyboard.layer == 1 and self.shifted:
      return self.shifted
    else:
      return self.symbol

class ShiftKey(Key):

  def __init__(self, scancode, name, symbol, layer_shift=1):
    super().__init__(scancode, name, symbol)
    self.layer_shift = layer_shift

  def on_press(self):
    self.keyboard.layer += self.layer_shift
    return True

  def on_release(self):
    self.keyboard.layer -= self.layer_shift
    return True

class ToggleKey(Key):
  def __init__(self, scancode, name, symbol):
    self.state = False
    super().__init__(scancode, name, symbol)

  def get_state(self):
    return self.state

  def on_press(self):
    self.state = not self.state
    setattr(self.keyboard, self.symbol, self.state)
    return True

class LongPressKey(Key):

  def __init__(self, scancode, name, symbol, long_press_sym, layers=None):
    super().__init__(scancode, name, symbol, layers=layers)
    self.long_press_sym = long_press_sym
    self.cancel_longpress = False
    self.tid = None

  def on_press(self):
    def callback():
      self.tid = None
      if self.keydown:
        keyboard.action(self, LONGPRESS, self.long_press_sym)

    self.tid = setTimeout(1, callback)

  def on_release(self):
    if self.tid is not None:
      cancelTimeout(self.tid)
      keyboard.action(self, PRESS, self.symbol)
      self.tid = None
    keyboard.action(self, RELEASE)


class Action:
  layer = 0
  def __init__(self, layer):
    self.layer = layer

  def on_press(self):
    return False

  def on_release(self):
    return False

class TwoLayerAction(Action):
  def __init__(self, main_callback, shifted_callback):
    self.callbacks = (main_callback, shifted_callback)
    super().__init__(1)

  def on_press(self):
    layer = keyboard.layer
    if layer < 2:
      cb = self.callbacks[layer]
      if callable(cb):
        return cb()
      else:
        print("Invalid callback: ",self,"callback=", cb)
        return True
    else:
      print("Unmatched layer:", layer)
      return False

  def on_release(self):
    return True
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

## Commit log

2025-10-09 PCB kicaed files
    [numpad-B_Cu.gbr, numpad-B_Mask.gbr, numpad-B_Silkscreen.gbr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]
2025-10-09 add pcb image

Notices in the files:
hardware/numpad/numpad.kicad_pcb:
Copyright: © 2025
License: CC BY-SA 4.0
